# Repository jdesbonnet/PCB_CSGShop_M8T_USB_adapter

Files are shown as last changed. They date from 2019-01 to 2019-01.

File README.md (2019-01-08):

# PCB_CSGShop_M8T_USB_adapter

USB adapter for [pin version of uBlox Neo-M8T](https://www.csgshop.com/product.php?id_product=240) available from CSGShop.

The pin header on the receiver breaks out USB D-/D+, 5V and GND. These can be routed directly to a USB mini or mico connector. For ease of construction I'm using a USB micro breakout board instead of soldering a USB micro connector directly on the board.

There are also headers for other pins including UART TX,RX (J4) and interrupt and timing pulse pins (J3).

PCB font

PCB back

## Version 1.0.1, 4 Jan 2019

* Fix missing trace to GND on M8T side of board. Easily patched on V1.0.0 board using a short bodge wire connection to neighboring J3 GND.
* Add extra info to silkscreen

## Version 1.0.0, Dec 2018

* First version.

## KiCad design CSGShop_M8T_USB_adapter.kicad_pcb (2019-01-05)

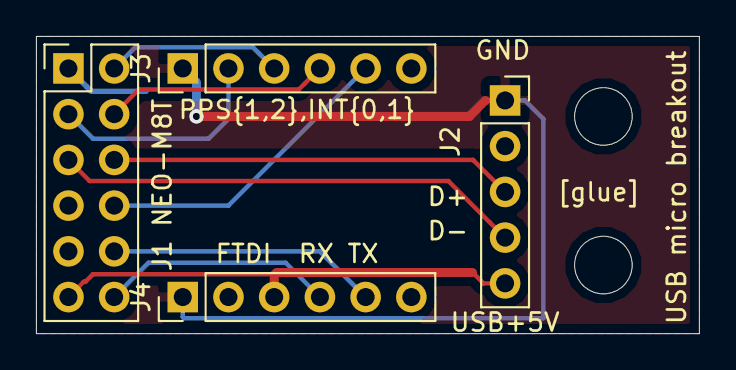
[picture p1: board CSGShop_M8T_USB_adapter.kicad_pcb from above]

Board: 2 copper layers, 36.8 x 16.5 mm, 4 parts (0 on the bottom side), 10 nets.

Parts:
J1 NEO-M8T: Conn_02x06_Odd_Even; PinHeader_2x06_P2.54mm_Vertical
J2: Conn_01x05; PinSocket_1x05_P2.54mm_Vertical
J3, J4: Conn_01x06_Male; PinHeader_1x06_P2.54mm_Vertical

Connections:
EXTINT0: J1 NEO-M8T.4, J3.4
EXTINT1: J1 NEO-M8T.8, J3.5
GND: J1 NEO-M8T.1, J2.1, J3.1, J4.1
PPS1: J1 NEO-M8T.3, J3.2
PPS2: J1 NEO-M8T.2, J3.3
RX: J1 NEO-M8T.12, J4.4
TX: J1 NEO-M8T.10, J4.5
USB+5V: J1 NEO-M8T.11, J2.5, J4.3
USB_DN: J1 NEO-M8T.5, J2.4
USB_DP: J1 NEO-M8T.6, J2.3

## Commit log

2018-12-10 PCB images
2019-01-05 version 1.0.0 (10 Dec 2018)
    [CSGShop_M8T_USB_adapter.kicad_pcb, CSGShop_M8T_USB_adapter.sch]
2019-01-05 fix missing trace to GND on M8T header
    [CSGShop_M8T_USB_adapter.kicad_pcb]
2019-01-05 add extra info on silk screen
    [CSGShop_M8T_USB_adapter.kicad_pcb]
